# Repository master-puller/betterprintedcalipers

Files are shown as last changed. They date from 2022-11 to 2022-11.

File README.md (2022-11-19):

# BetterPrintedCalipers (BPC v0)
### Designed in FreeCAD
This project attempts to solve the downfalls of regular 3D printed calipers regarding flex, smoothness of motion and repeatability. I won't pretend that this will be a perfect pair of calipers (If you want some, Mititoyo!), but this should be "good enough" for most measurements.

This design is meant to be used like vernier calipers, but you print your own scales, which allows printers that aren't super dimensionally accurate to create this. Side note: this can possibly also serve as a slide rule with the correct scales

Backlash is eliminated with the use of recirculating ball bearings embedded in the calipers, with adjustable spacing.

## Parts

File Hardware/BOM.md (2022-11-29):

BOM for Better-Printed Calipers

- [ ] x2 M3 5mm bolts
- [ ] x2 M3 Square nuts
- [ ] x1 Printed Scale
- [ ] x2 Printed Vernier
- [ ] x60 3/32 in bearing balls (BRING MORE!)
- [ ] x1 Sliding Jaw Base
- [ ] x1 Sliding Jaw bearing
- [ ] x1 Fixed Jaw

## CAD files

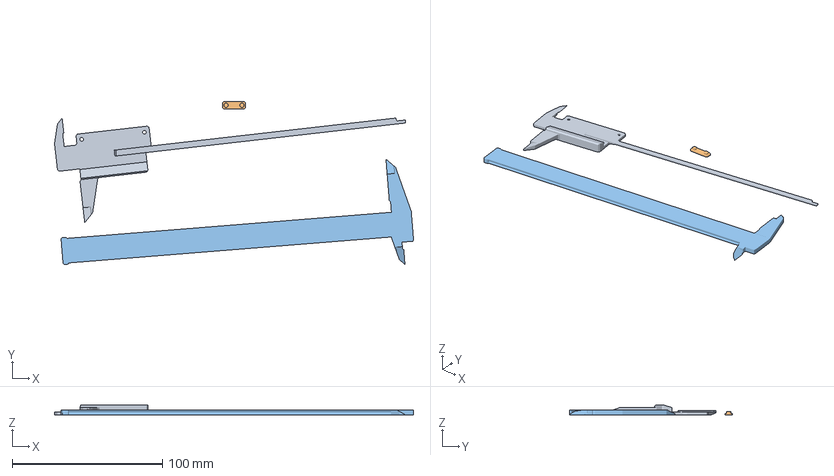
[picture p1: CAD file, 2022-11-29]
3D printing/3MF/bpc_calipers_whole.3mf
239.2 x 108.6 x 6.84 mm
vernier_calipers-Moving JawChamfer007.stl
part_bpc_clip.stl
part_bpc_slidingjaw.stl

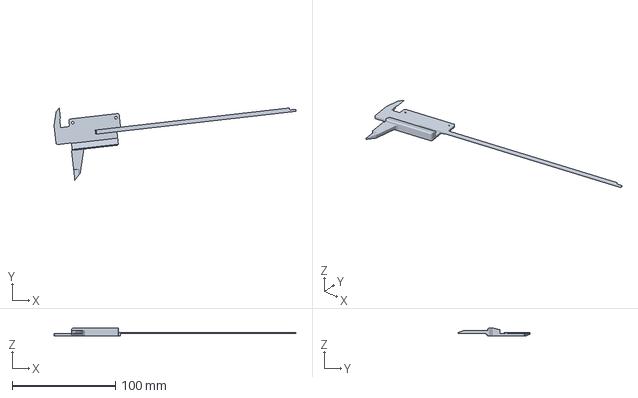
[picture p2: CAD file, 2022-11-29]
3D printing/3MF/part_bpc_fixedjaw.3mf
234.0 x 69.7 x 7.26 mm

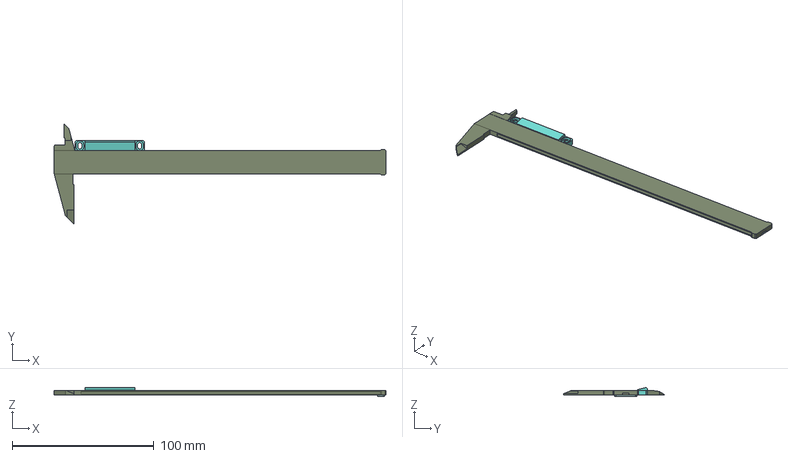
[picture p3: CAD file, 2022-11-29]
Hardware/vernier_calipers.FCStd
234.0 x 71.0 x 6.35 mm
Moving Jaw
Depth Gauge Support
Fixed Jaw

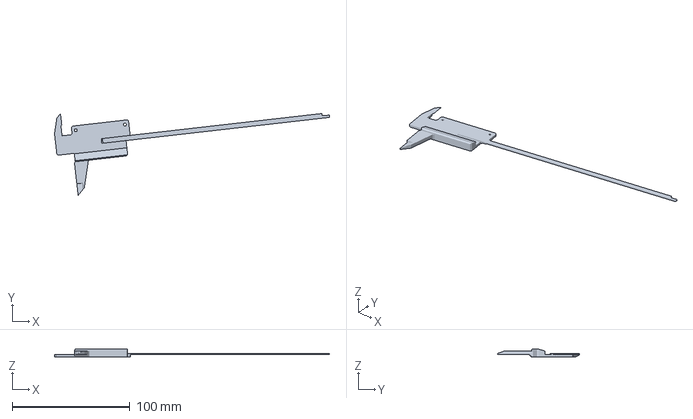
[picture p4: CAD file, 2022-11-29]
3D printing/3MF/bpc_calipers_afteradjust.3mf
234.0 x 69.7 x 6.84 mm

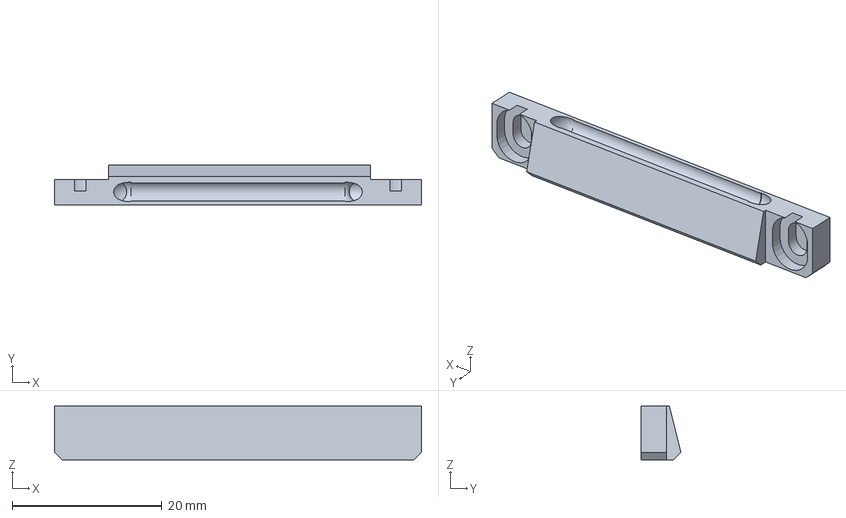
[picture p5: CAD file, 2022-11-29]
3D printing/3MF/part_bpc_movablebearing.3mf
49.0 x 5.35 x 7.20 mm

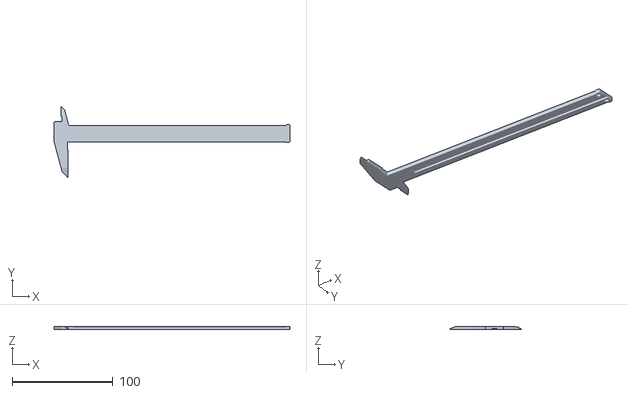
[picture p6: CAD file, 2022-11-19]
3D printing/3MF/part_bpc_slidingjaw.stl
234.0 x 71.0 x 3.40

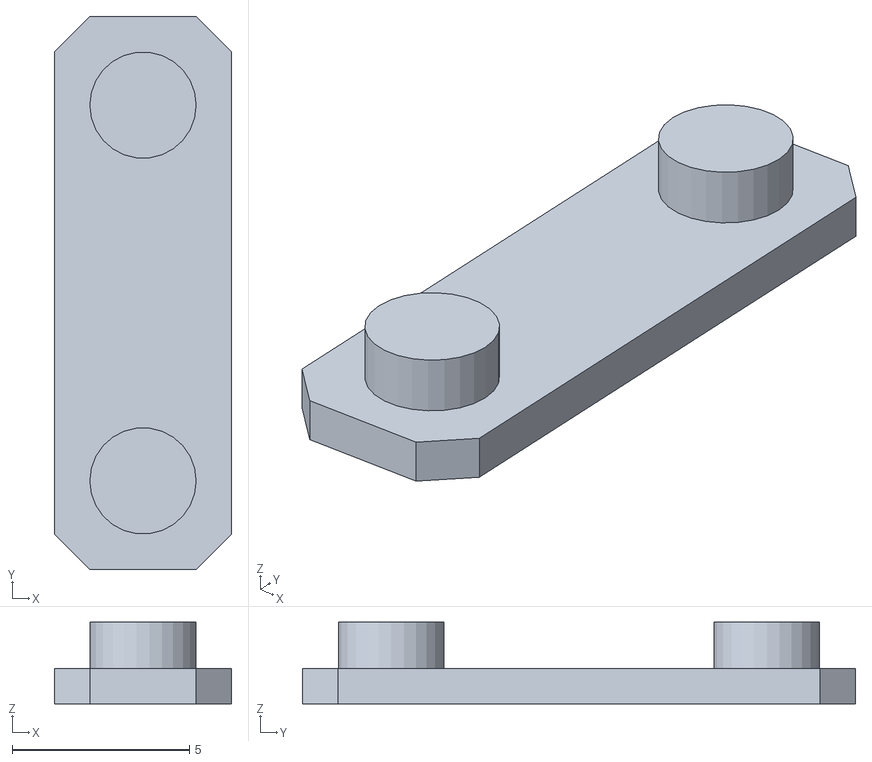
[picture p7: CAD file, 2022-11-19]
3D printing/3MF/part_bpc_clip.stl
5.00 x 15.6 x 2.30

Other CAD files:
3D printing/3MF/part_bpc_fixedjaw.stl

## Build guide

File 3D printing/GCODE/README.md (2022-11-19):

# Gcode README
These files are gcodes kept in this folder for backup purposes. No gcodes in this folder are guaranteed to work on your printer, as they are sliced for my Prusa.
If you want to print these files, use the 3MF folder instead. It has all the necessary modifications to print well. These files will also likely be not up-to-date.

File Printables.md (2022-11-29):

I've wanted to do this project ever since I saw several attempts at 3D printed calipers, all of which said that this was a novelty. I didn't want for it to be that way, and I decided to create an instrument, that once calibrated, is worthy of your trust. 

These had various downfalls, from having too much backlash, to not being reliable in measurements, I'm attempting to address these features and make a reliable tool that costs pennies to create. (Meaning: You can abuse them like all the other cheap calipers you have been doing) This project stems from the DPI of 2D printers, which allows for very accurate graduations and distances.

As an upside of the approach incorporating ball bearings, the calipers require less force to move than a comparable set of steel calipers (which may or may not be undesirable)

Hardware: Copied from BOM.MD
x2 M3x5 Screws
x2 M3x5 Square nuts (Included with Prusa Spare parts)
x60 3/32" ball bearings (BRING MANY MORE!)

##Guide to printing:

1. Please use at largest a .4mm nozzle. You could do it, who's stopping you, but I don't recommend it at any larger
2. Printing external perimeters first may improve tolerances, you will have to redo any print calibration
3. Print all the parts at 50% layer height or less. My recommended value is .15 mm, as it gives a good balance between speed and quality (for this application)
4. Print the calibrator first! Then set the value of XY offset for all the parts and print. Tolerance coins may be useful at guesstimating, but vertical print compensation is not included.

(Link to Hackaday.io Project)[https://hackaday.io/project/188295-better-printed-calipers]
(Most Recent Iterations on Github)[https://github.com/master-puller/betterprintedcalipers]

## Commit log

2022-11-19 Reorganize Project Structure
    [bpc_calipers_whole.3mf, part_bpc_clip.stl, part_bpc_fixedjaw.stl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]
2022-11-29 Parameterization of CAD
    Add .gitignore, first version of the printable scale
    [bpc_calipers_afteradjust.3mf, bpc_calipers_whole.3mf, part_bpc_fixedjaw.3mf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]
